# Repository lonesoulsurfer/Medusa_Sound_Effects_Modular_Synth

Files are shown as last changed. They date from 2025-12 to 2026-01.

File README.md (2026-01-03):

YJPQ4857

YouTube - https://youtu.be/EX9xcyuSX-U

Instructables - Step by step guide - https://www.instructables.com/Medusa-a-Sound-Effects-Synth-Eurorack-Module-or-St/

4 Main Knobs:

         Pot 1 (Pitch) - Controls the base frequency/note
    
         Pot 2 (Speed) - Controls how fast things move (LFO speed, tempo, etc.)

         Pot 3 (Modulation) - Controls effect intensity (vibrato, filter, etc.)
    
         Pot 4 (Echo Feedback) - Controls how much echo/delay repeats

Main Buttons:

          TRIGGER - Hold to play sound
          
          MENU - Cycles through 4 instruments (Dub Siren → Ray Gun → Lead Synth → Disco)
          
          MODE - Changes the sound variation within each instrument
          
         DELAY - Cycles delay time (OFF → 50ms → 100ms → 175ms → 250ms → 375ms)
         
          GATE - Changes gate length (how long notes are)
          
          OCTAVE - Shifts pitch up/down by octaves
          
          MUTATE - Cycles mutation modes (makes sound evolve randomly on each sync in trigger)

More details on the Mutate Function:

           Mutate works only with pitch and is controled by the pitch knob
           
           It will also only work with a sync in

           There are 3 sub menus
           
          1.  Mutation Probability (0-100%)
           
          2.  Rhythm - controls musical Scale Selection Cycles through: MIN PENT → MAJOR → BLUES → MINOR

          3.  Cutoff - Filter Cutoff (200-4000Hz)

           Mutate can be turned off by double tapping the mutate button and turned back on by tapping the mutate button
           Each function once set, is locked into place.

8 Keyboard Keys:

         Press keys 1-8 to play different notes in a musical scale

         Works like a mini keyboard - each key plays a specific pitch

         Also activates the special features

Instrument Guide

 1. DUB SIREN (Classic reggae/dub swoops)

         What each pot does:
         
         Pot 1 (PITCH) - Base frequency (50-2000Hz) - turn to change the note

         Pot 2 (SPEED) - LFO speed (0.1-20Hz) - how fast the sound wobbles

         Pot 3 (MOD) - Modulation depth (0-100%) - how much the pitch sweeps

         Pot 4 (Echo Feedback) - Echo repeats (0-95%) - for dub delays

6 Modes (press MODE button):

         CLASSIC DUB - Smooth sawtooth wobble
         
         DEEP SUB - Adds sub-bass octave (Pot 3 controls sub mix)
         
         SQUARE WAVE - Hollow, aggressive tone
         
         LO-FI CRUSH - Bit crusher effect (Pot 3 controls bit depth 1-8)
         
         RING MOD - Metallic ring modulation (Pot 3 controls ring mod frequency)
         
         PORTAMENTO - Smooth pitch glide (Pot 2 controls glide time)

2. RAY GUN (Sci-fi laser sounds)

         What each pot does:

         Pot 1 (FREQ) - Laser frequency (200-4000Hz) - pitch of the laser

         Pot 2 (SWEEP) - Sweep speed (0.1-20Hz) - how fast it swoops

         Pot 3 (RES) - Resonance (30-95%) - filter sharpness/brightness

         Pot 4 (Echo Feedback) - Echo repeats (0-95%)

         4 Modes (press MODE button):

         ZAP - Quick upward sweep (classic ray gun)

         LASER - Downward sweep with noise burst

         BLASTER - Rapid fire short bursts

         PHASER - Modulated pulse (sci-fi phaser)

3. LEAD SYNTH (Generative melodies)

         What each pot does:

         Pot 1 (ROOT) - Root note (200-800Hz) - base pitch of the melody

         Pot 2 (TEMPO) - Step speed (100-1000ms) - how fast notes play

         Pot 3 (VIB) - Vibrato depth (0-10%) - pitch wobble on notes

         Pot 4 (Gate) - Gate length (20-100%) - how long each note plays

         4 Modes (press MODE button):

         SEQUENCE - Plays pre-programmed melody

         ARPEGGIO - Arpeggiator with octave jumps

         EUCLIDEAN - Euclidean rhythm patterns

         GENERATIVE - Auto-generates new melodies

4. DISCO (Classic disco effects)

         What each pot does:

         Pot 1 (PITCH) - Base frequency (100-2000Hz) - effect pitch

         Pot 2 (SPEED) - Effect duration/speed - how long the effect lasts

         Pot 3 (BRIGHT) - Brightness (0-100%) - filter cutoff/tone

         Pot 4 (Echo Feedback) - Echo repeats (0-95%)

         6 Modes (press MODE button):

         ORCH HIT - Punchy orchestral stab

         STRINGS - Rising string machine sweep

         FUNK BLAST - Synth brass stab with pitch bend

         WHOOSH - Noise sweep (spaceship flyby)

         BUBBLE - Percussive bubble pop sound

         LASER - Musical laser sweep with vibrato

Special Features (Function + key buttons 1 - 8)

Sequencer  (Function + Key 1):

         Creates an 8-step programmable sequence

         Press keyboard keys to toggle steps on/off

         Hold a key to adjust that step's pitch with Pot 1

         TRIGGER starts/stops playback

Record  (Function + Key 3):

         Press Key 3 once to start recording (up to 5 seconds)

         Press Key 3 again to stop

         Press Key 3 again to play back

         Press Key 4 to toggle loop on/off

Reverse  (Function + Key 4):

         Press Key 4 to toggle reverse effect on/off

         Pot 1 controls pitch shift

         Pot 3 controls wet/dry mix

Infinite Delay (Function + Key 5):

         Press Key 5 to toggle infinite sustain on/off

         Pot 1: Feedback amount (95-100%) when hold is ON

         Pot 3: Filter cutoff

LFO 2 (Function + Key 6)

         Secondary LFO that modulates frequency for vibrato/tremolo effects

         Pot 1: LFO 2 Rate (0.1-20 Hz)

         Pot 3: LFO 2 Depth (0-100%)

         Press Key 6 to toggle LFO 2 ON/OFF

Drone (Function + Key 7)

         5-oscillator additive drone synthesizer with drift and detuning

         Press TRIGGER to cycle modes: OFF → KEYS → ON
         
         Pot 1: Root Pitch (20-400Hz)

         Pot 2: Detune Amount (0-100%) - spread between oscillators

         Pot 3: Brightness (0-100%) - timbre from dark to bright

         Pot 4: Drift Speed (0.1-5Hz) - slow LFO modulation

                  Press MODE button to cycle chord voicings:

                           UNISON: All oscillators at same pitch

                           OCTAVE: Root + octaves

                           FIFTH: Root + perfect fifth

                           MAJOR: Major chord (root, major 3rd, 5th)

                           MINOR: Minor chord (root, minor 3rd, 5th)

Sidechain (Function + Key 8)

         Classic "pumping" sidechain compression effect

         Press Key 8 to toggle SIDECHAIN ON/OFF

         Pot 1: Ducking Depth (0-100%) - how much volume reduction

         Pot 2: Attack Time (1-50ms) - how fast it ducks

         Pot 3: Release Time (50-500ms) - how fast it returns

         Syncs with LOOP patterns or SYNC input for rhythmic pumping

         Auto-retriggering creates continuous pumping effect

NOTE - all functions can be turned off by double tapping the Function button

EBXY7489

GSUT3404

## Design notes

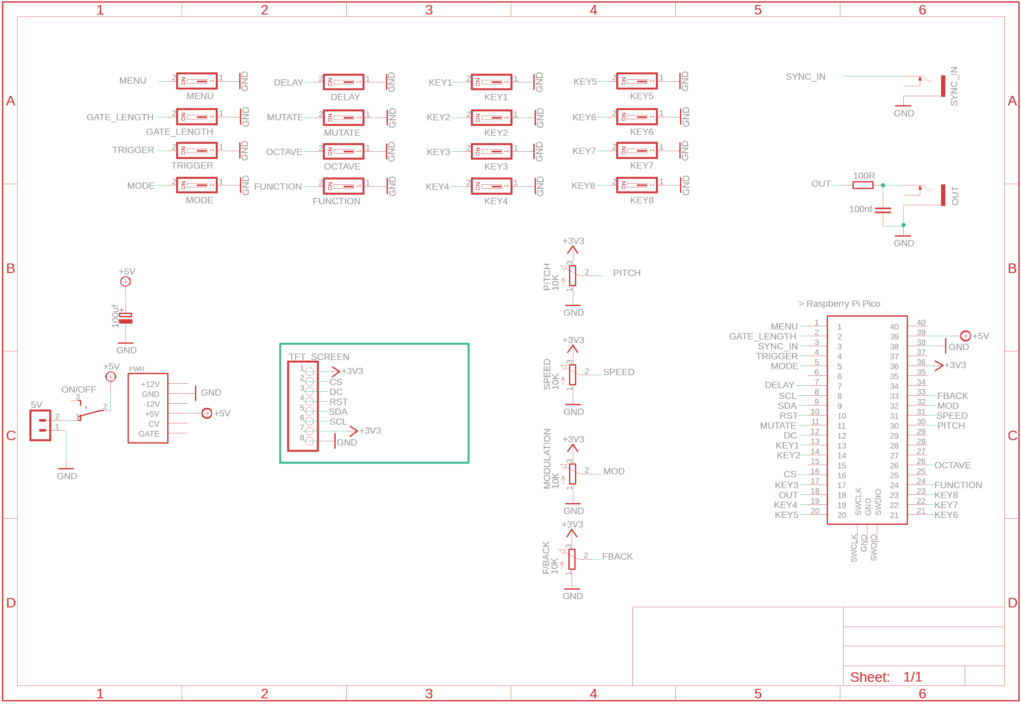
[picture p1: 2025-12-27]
Schematic.png

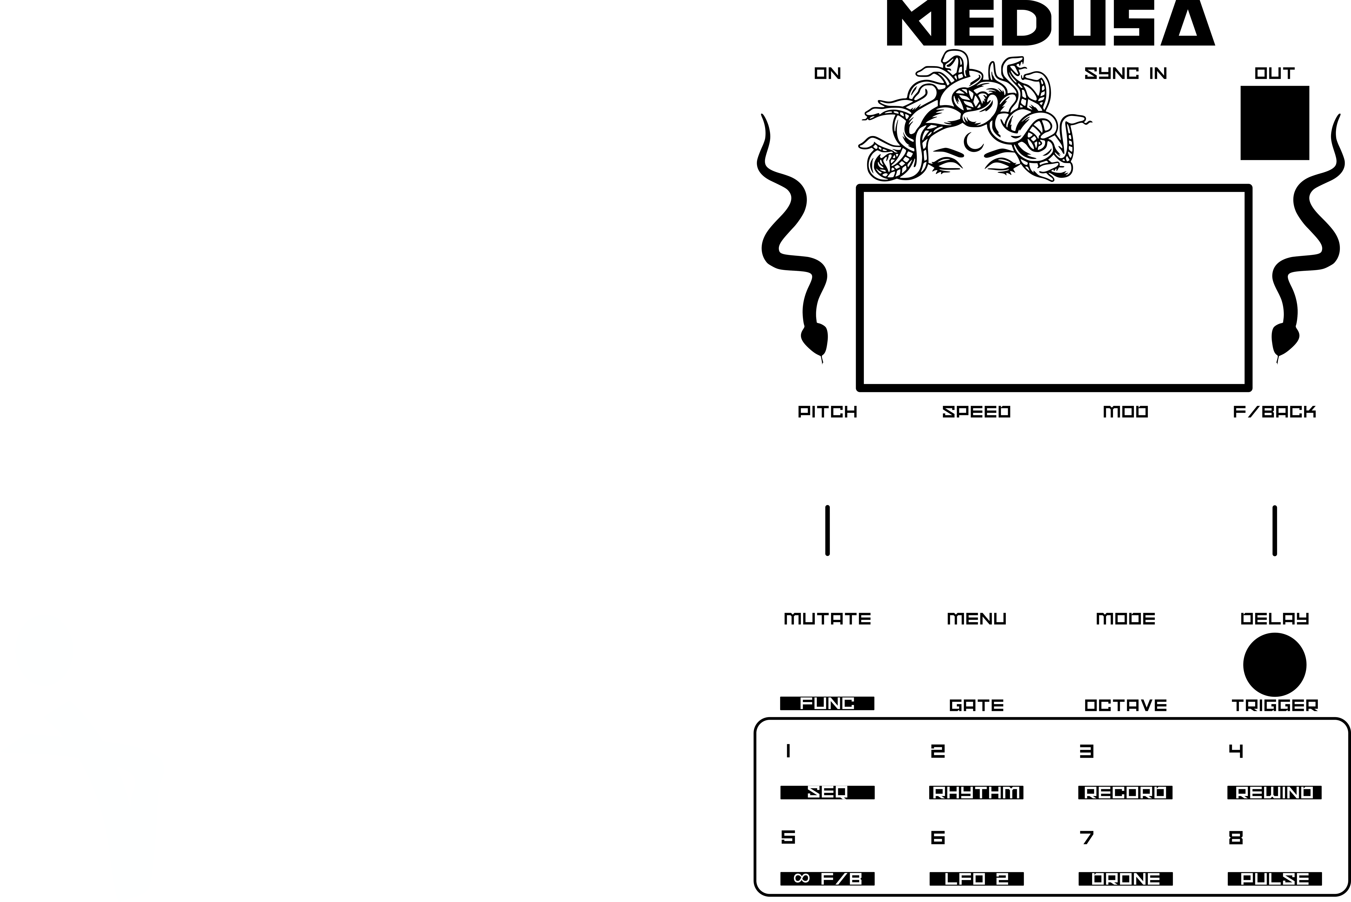
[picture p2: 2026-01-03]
Front Panel Design/Medusa -Front Panel Inkscape.png

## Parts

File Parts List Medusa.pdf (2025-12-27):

Part | Type | Part Number | Value | Qty | Link | Image
Mini JST Connector and wire | 2 pin | | 2 | 1 | Link (https://vi.aliexpress.com/item/1005005939956886.html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)
Capacitor | Polyester | | 100nf | 1 | Link (https://vi.aliexpress.com/w/wholesale-capacitor-100nf.html?spm=a2g0o.productlist.search.0)
| Electrolytic | | 100uf | 1 | Link (https://vi.aliexpress.com/w/wholesale-capacitor-100uf-.html?spm=a2g0o.productlist.search.0)
Switch | Momentary | SKRCADD010 | | 16 | Link (https://www.aliexpress.com/w/wholesale-SKRCADD010.html?spm=a2g0o.productlist.search.0)
| SPDT - Through Hole Version | | | 1 | Link (https://vi.aliexpress.com/item/1005001510219617.html)
Potentiometer | Verticle 9mm - Use the metal sharft type. You can use the nut on these to help secure the front panel to the PCB | | 10K | 4 | Link (https://www.aliexpress.com/w/wholesale-9mm-vertical-potentiometer.html)
Raspberry Pi Pico | Note that I used the Raspberry Pi that has 4 analog inputs. You need to get the exact one. See picture | | | 1 | Link (https://www.aliexpress.com/item/1005008614073097.html?curPageLogUid=pEBG9kNp92hi)
Female Header Pin Socket | 20 Pin | | | 3 | Link (https://vi.aliexpress.com/w/wholesale-Single-Row-Female-2.54MM-Spacing-Pin.html)
Male Header Pin | 7 Pin. These are used for the screen. The pins are 0.5mm | | | 1 | Link
Female header pin | 7 Pin. These are used for the screen. The pins are 0.5mm | | | 1 | Link
Audio Socket | | PJ301M | | 2 | Link (https://vi.aliexpress.com/item/1005005352992401.html?scm_id=1007.40050.354490.0&scm-url=1007.40050.354490.0)
Resistor | Metal film 1% | | 270R | 1 | Link (https://vi.aliexpress.com/w/wholesale-resistor-metal-film.html?spm=a2g0o.productlist.search.0)
TFT Screen | 1.9 Inch, 170x320 ST7789 | | | 1 | Link (https://www.aliexpress.com/w/wholesale-1.9-Inch-IPS-Full-Angle-TFT-Display-Screen-LCD-Scr.html)
M2 screws | | | | | Link (https://www.aliexpress.com/item/1005007159750547.html)
M2 Spacers | Nylon | | | | Link (https://www.aliexpress.com/w/wholesale-Nylon-Hex-Hexagon-Spacer-Column-Standoff-m2.html)

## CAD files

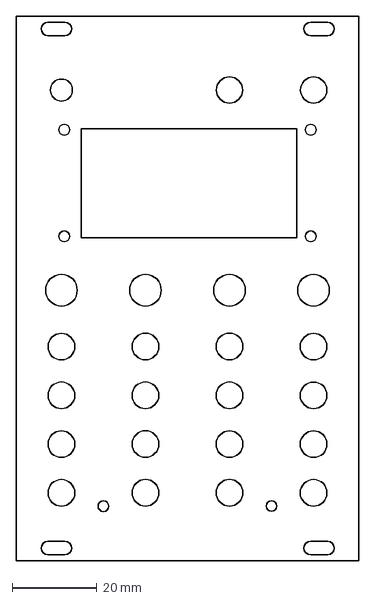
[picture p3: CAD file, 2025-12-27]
Front Panel Design/Medusa - Fusion.dxf
80.9 x 128.5 mm

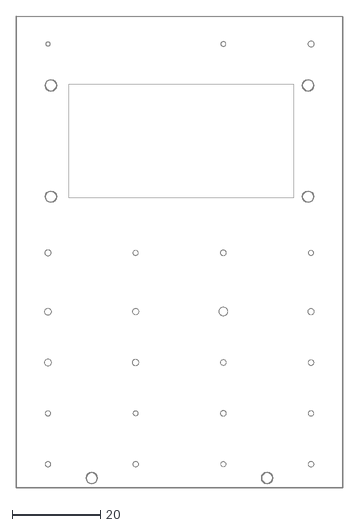
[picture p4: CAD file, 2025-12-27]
Front Panel Design/Medusa PCB.dxf
73.9 x 106.6

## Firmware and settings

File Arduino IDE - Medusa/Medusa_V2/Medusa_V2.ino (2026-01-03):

/*
 * =====================================================================
 *                    RP2040 DUB SIREN
 *              with Real-time Waveform Display
 *              RP2040-Zero + ST7789 170x320 TFT
 * =====================================================================
 * 
 * HARDWARE:
 * Waveshare RP2040-Zero
 * ST7789 170x320 TFT Display
 * 4 Potentiometers (10k recommended)
 * 2 Buttons (momentary)
 * Audio out via PWM
 * 
 * WIRING:
 * TFT Display:
 *   SCL -> GP6, SDA -> GP7
 *   RST -> GP8, DC -> GP10, CS -> GP13
 * 
 * Potentiometers (to 3.3V and GND):
 *   Pot 1 (Pitch)         -> GP26 (ADC0)
 *   Pot 2 (Speed)         -> GP27 (ADC1)
 *   Pot 3 (Modulation)    -> GP28 (ADC2)
 *   Pot 4 (Echo Feedback) -> GP29 (ADC3)
 * 
 * Buttons:
 *   Trigger Button (momentary) -> GP3
 *   Delay Time Button          -> GP5 (cycles through 5 delay times)
 *   Mode Button                -> GP4 (cycles through synthesis modes)
 * 
 * Sync Input:
 *   External Sync (3-5V)       -> GP2 (triggers sound when HIGH)
 * 
 * Audio Output:
 *   PWM Audio -> GP15 -> 100Ω resistor -> amplifier input
 * =====================================================================
 */

#include <SPI.h>
#include <Adafruit_GFX.h>
#include <Adafruit_ST7789.h>
#include <hardware/pwm.h>
#include <hardware/adc.h>

// =====================================================================
// PIN DEFINITIONS
// =====================================================================

// Display pins
#define TFT_CS        13
#define TFT_RST       8
#define TFT_DC        10
#define TFT_MOSI      7
#define TFT_SCK       6

// Potentiometer pins (ADC)
#define POT_PITCH     26  // ADC0
#define POT_SPEED     27  // ADC1
#define POT_MOD       28  // ADC2 - Modulation depth
#define POT_FEEDBACK  29  // ADC3 - Echo feedback

// Button pins
#define BTN_TRIGGER   3
#define BTN_DELAY     5   // Cycles through delay times
#define BTN_MODE      4   // Cycles through synthesis modes
#define BTN_FUNCTION  1   // Multi-function button (gate length, etc)
#define BTN_MENU      0   // MENU BUTTON - cycles instruments
#define BTN_MUTATE    9   // MUTATE BUTTON - cycles mutation modes
#define BTN_FUNC_SHIFT 21 // FUNCTION SHIFT - hold for alternative key functions

// Sync input
#define SYNC_IN       2   // External sync input (3-5V triggers sound)

// Keyboard pins (8 keys)
#define KEY_1         11  // Root note
#define KEY_2         12  // 2nd degree
#define KEY_3         14  // 3rd degree
#define KEY_4         16  // 4th degree
#define KEY_5         17  // 5th degree
#define KEY_6         18  // 6th degree
#define KEY_7         19  // 7th degree
#define KEY_8         20  // Octave/8th degree

// Octave shift button
#define BTN_OCTAVE    23  // Cycles octave shift

// Audio pin
#define AUDIO_PIN     15

// Display dimensions
#define SCREEN_WIDTH  320
#define SCREEN_HEIGHT 170

// Colors
#define COLOR_BG      0x0000
#define COLOR_WAVE    0x07E0  // Green
#define COLOR_GRID    0x2104  // Dark green
#define COLOR_TEXT    0xFFFF
#define COLOR_ACTIVE  0xF800  // Red
#define COLOR_ECHO    0x07FF  // Cyan
#define COLOR_MOD     0xFFE0  // Yellow

// =====================================================================
// AUDIO CONFIGURATION
// =====================================================================

#define SAMPLE_RATE 22050
#define PWM_WRAP 255

// Echo buffer - 500ms max delay at 22050 Hz
#define MAX_DELAY_SAMPLES 11025
int16_t echoBuffer[MAX_DELAY_SAMPLES];
uint16_t echoWritePos = 0;

// =====================================================================
// FORWARD DECLARATIONS
// =====================================================================

/**
 * Draw a labeled parameter value with color-coded label
 * @param x X position
 * @param y Y position
 * @param width Width of clear area
 * @param label Label text (will be colored MOD color)
 * @param value Value to display
 * @param suffix Optional suffix (Hz, ms, %, etc)
 * @param valueColor Color for value text (default: TEXT)
 */

void drawParameter(int x, int y, int width, const char* label, const char* value, const char* suffix = "", uint16_t valueColor = COLOR_TEXT);
void drawParameter(int x, int y, int width, const char* label, int value, const char* suffix = "", uint16_t valueColor = COLOR_TEXT);
void drawSubHeading(int y, const char* label, const char* value, uint16_t valueColor = COLOR_TEXT);
void drawSubHeadingOctave(int y, int8_t octaveValue);
void drawSubHeadingGatePercent(int y, uint8_t percentage);
void drawWaveform(bool forceRedraw = false);
void drawParameters(bool forceFullRedraw = false);
void updateKeyboardFrequencies();
void generateMelody();
float quantizePitchToScale(float baseFreq, uint8_t scaleStep);

// =====================================================================
// GLOBAL OBJECTS
// =====================================================================

Adafruit_ST7789 display = Adafruit_ST7789(&SPI, TFT_CS, TFT_DC, TFT_RST);
uint slice_num;

// =====================================================================
// INSTRUMENT TYPES
// =====================================================================

enum InstrumentType {
    INST_DUB_SIREN = 0,
    INST_RAY_GUN,
    INST_LEAD_SYNTH,
    INST_DISCO,
    INST_COUNT
};

const char* instrumentNames[INST_COUNT] = {
    "DUB SIREN",
    "RAY GUN",
    "LEAD SYNTH",
    "DISCO"
};

// =====================================================================
// SYNTHESIS MODES
// =====================================================================

enum SynthMode {
    MODE_CLASSIC_DUB = 0,
    MODE_DEEP_SUB,
    MODE_SQUARE_WAVE,
    MODE_LOFI_CRUSH,
    MODE_RING_MOD,
    MODE_PORTAMENTO,
    MODE_COUNT
};

const char* modeNames[MODE_COUNT] = {
    "CLASSIC DUB",
    "DEEP SUB",
    "SQUARE WAVE",
    "LO-FI CRUSH",
    "RING MOD",
    "PORTAMENTO"
};

// Ray Gun sub-modes
enum RayGunMode {
    RAYGUN_ZAP = 0,      // Quick upward sweep
    RAYGUN_LASER,        // Downward sweep
    RAYGUN_BLASTER,      // Short burst
    RAYGUN_PHASER,       // Modulated pulse
    RAYGUN_MODE_COUNT
};

const char* rayGunModeNames[RAYGUN_MODE_COUNT] = {
    "ZAP",
    "LASER",
    "BLASTER",
    "PHASER"
};

// Lead Synth sub-modes
enum LeadSynthMode {
    LEAD_SEQUENCE = 0,    // Auto-sequenced melody
    LEAD_ARPEGGIO,        // Arpeggiator
    LEAD_EUCLIDEAN,       // Euclidean rhythm patterns
    LEAD_GENERATIVE,      // Generative melody
    LEAD_MODE_COUNT
};

const char* leadSynthModeNames[LEAD_MODE_COUNT] = {
    "SEQUENCE",
    "ARPEGGIO",
    "EUCLIDEAN",
    "GENERATIVE"
};

// Disco sub-modes
enum DiscoMode {
    DISCO_ORCHESTRA_HIT = 0,  // Punchy orchestral stab
    DISCO_STRING_SWEEP,       // Rising string machine
    DISCO_FUNK_BLAST,         // Synth brass stab
    DISCO_SPACE_WHOOSH,       // Noise sweep (spaceship)
    DISCO_BUBBLE_POP,         // Percussive bubble sound
    DISCO_LASER_SWEEP,        // Musical laser sweep
    DISCO_MODE_COUNT
};

const char* discoModeNames[DISCO_MODE_COUNT] = {
    "ORCH HIT",
    "STRINGS",
    "FUNK BLAST",
    "WHOOSH",
    "BUBBLE",
    "PAD CHORD"
};

// Mutation modes
enum MutationMode {
    MUTATE_OFF = 0,
    MUTATE_AMOUNT,
    MUTATE_RHYTHM,
    MUTATE_CUTOFF,
    MUTATE_MODE_COUNT
};

const char* mutationModeNames[MUTATE_MODE_COUNT] = {
    "OFF",
    "MUTATE",
    "RHYTHM",
    "CUTOFF"
};

// Loop/Gate pattern modes
enum LoopPattern {
    LOOP_OFF = 0,
    LOOP_TRIPLET,    // ███░░░███░░░ (triplet feel - 3 against 2)
    LOOP_SWING,      // ██░██░░██░ (swing/shuffle - classic dub feel)
    LOOP_STACCATO,   // █░░█░░█░░ (short stabs)
    LOOP_GATE,       // ████░░░░ (gate on first half, off second)
    LOOP_RATCHET,    // █░█░█░█░█░█░ (fast machine gun)
    LOOP_DOTTED,     // ██░█░██░█░ (dotted eighth feel)
    LOOP_COUNT
};

const char* loopPatternNames[LOOP_COUNT] = {
    "OFF",
    "TRIPLET",
    "SWING",
    "STACCATO",
    "GATE",
    "RATCHET",
    "DOTTED"
};

// Loop pattern state
struct LoopState {
    bool active;                  // Is loop mode active?
    uint8_t pattern;              // Current loop pattern
    unsigned long patternStartTime; // When current pattern cycle started
    uint16_t patternTempo;        // Pattern speed in ms (full cycle time)
    bool gateState;               // Current gate on/off state
};

LoopState loopState = {
    false,        // active
    LOOP_OFF,     // pattern
    0,            // patternStartTime
    480,          // patternTempo (480ms = 125 BPM, classic dub tempo)
    false         // gateState
};

// =====================================================================
// SEQUENCER STATE
// =====================================================================

struct SequencerState {
    bool active;              // Is sequencer mode active?
    bool running;             // Is sequencer playing?
    bool stepEnabled[8];      // Which steps are on/off
    float stepFrequencies[8]; // Frequency for each step
    uint8_t currentStep;      // Current playback position (0-7)
    unsigned long lastStepTime; // Timing for steps
    uint16_t stepInterval;    // ms between steps (from Pot 2)
    bool noteActive;          // Is current note playing
    uint32_t sequencerPhase;  // Sequencer oscillator phase
    uint8_t gateLength;       // Gate length percentage (20-100%)
    unsigned long noteStartTime; // When current note started
    uint16_t filterCutoff;    // Filter cutoff frequency (200-4000)
    int8_t octaveShift;       // Octave shift for sequencer (-2 to +2)
    uint8_t soundMode;        // Sound variation mode
};

SequencerState sequencer = {
    false,                    // active
    false,                    // running
    {true, true, true, true, true, true, true, true}, // All steps enabled initially
    {0,0,0,0,0,0,0,0},       // stepFrequencies (will be set from keyboard)
    0,                        // currentStep
    0,                        // lastStepTime
    250,                      // stepInterval (250ms default)
    false,                    // noteActive
    0,                        // sequencerPhase
    80,                       // gateLength (80% default)
    0,                        // noteStartTime
    1200,                     // filterCutoff (1200 default - warm tone)
    0,                        // octaveShift (start at 0)
    0                         // soundMode (SAW mode default)
};

// Sequencer sound modes
enum SequencerSoundMode {
    SEQ_SOUND_SAW = 0,     // Sawtooth/square mix (current)
    SEQ_SOUND_PULSE,       // Pulse width modulation
    SEQ_SOUND_FILTERED,    // Heavy filtered bass
    SEQ_SOUND_PLUCK,       // Plucked envelope
    SEQ_SOUND_CHORD,       // Add 5th harmonic
    SEQ_SOUND_COUNT
};

const char* seqSoundModeNames[SEQ_SOUND_COUNT] = {
    "SAW",
    "PULSE",
    "FILTERED",
    "PLUCK",
    "CHORD"
};

// Musical scales for pitch quantization (frequency ratios)
const float minorPentatonic[] = {1.0f, 1.189f, 1.335f, 1.498f, 1.782f, 2.0f}; // Root, m3, 4, 5, m7, octave
const uint8_t minorPentatonicSize = 6;

const float majorScale[] = {1.0f, 1.122f, 1.260f, 1.335f, 1.498f, 1.682f, 1.888f, 2.0f}; // Major scale
const uint8_t majorScaleSize = 8;

const float bluesScale[] = {1.0f, 1.189f, 1.260f, 1.335f, 1.498f, 1.782f, 2.0f}; // Blues scale
const uint8_t bluesScaleSize = 7;

const float minorScale[] = {1.0f, 1.122f, 1.189f, 1.335f, 1.498f, 1.587f, 1.782f, 2.0f}; // Natural minor
const uint8_t minorScaleSize = 8;

const float chromaticScale[] = {1.0f, 1.059f, 1.122f, 1.189f, 1.260f, 1.335f, 1.414f, 1.498f, 1.587f, 1.682f, 1.782f, 1.888f, 2.0f}; // All 12 notes
const uint8_t chromaticScaleSize = 13;

// Musical scales for mutation
enum MutationScale {
    SCALE_MINOR_PENT = 0,
    SCALE_MAJOR,
    SCALE_BLUES,
    SCALE_MINOR,
    SCALE_CHROMATIC,
    SCALE_COUNT
};

const char* scaleNames[SCALE_COUNT] = {
    "MIN PENT",
    "MAJOR",
    "BLUES",
    "MINOR",
    "CHROMATIC"
};

// Mutation state
struct MutationState {
    uint8_t mode;           // Current mutation mode
    uint8_t pitchStep;      // Current step in scale
    uint8_t speedStep;      // Current speed quantization step
    float mutationProbability; // Chance of mutation (0.0-1.0)
    unsigned long lastMutateTime; // Last time mutation occurred
    uint8_t currentScale;   // Current scale being used
    
    // Parameter locking
    uint16_t lockedProbabilityRaw;  // Locked pot value for probability
    uint16_t lockedScaleRaw;        // Locked pot value for scale
    uint16_t lockedCutoffRaw;       // Locked pot value for cutoff
    bool probabilityLocked;         // Is probability parameter locked?
    bool scaleLocked;               // Is scale parameter locked?
    bool cutoffLocked;              // Is cutoff parameter locked?
    bool fullyDisabled;             // Are all mutations disabled? (ADD THIS LINE)
};

MutationState mutate = {
    MUTATE_OFF,     // mode
    0,              // pitchStep (start at root)
    2,              // speedStep (start at medium speed)
    0.5f,           // mutationProbability (50% chance)
    0,              // lastMutateTime
    SCALE_MINOR_PENT, // currentScale (minor pentatonic default)
    
    // Initialize locks
    2048,           // lockedProbabilityRaw (middle position)
    2048,           // lockedScaleRaw (middle position)
    2048,           // lockedCutoffRaw (middle position)
    false,          // probabilityLocked
    false,          // scaleLocked
    false,          // cutoffLocked
    false           // fullyDisabled (ADD THIS LINE)
};

// Drone chord modes
enum DroneChordMode {
    DRONE_UNISON = 0,
    DRONE_OCTAVE,
    DRONE_FIFTH,
    DRONE_MAJOR,
    DRONE_MINOR,
    DRONE_CHORD_COUNT
};

const char* droneChordModeNames[DRONE_CHORD_COUNT] = {
    "UNISON",
    "OCTAVE",
    "FIFTH",
    "MAJOR",
    "MINOR"
};

// Drone synth state
struct DroneState {
    bool active;              // Is drone mode active?
    uint8_t playMode;         // Play mode: 0=OFF, 1=KEYS, 2=ON
    float rootFreq;           // Base frequency (20-400Hz)
    float detune;             // Detune amount (0.0-1.0)
    float brightness;         // Timbre control (0.0-1.0)
    float driftSpeed;         // LFO drift rate (0.1-5Hz)
    uint32_t oscPhases[5];    // Phase accumulators for each oscillator
    float oscDetunes[5];      // Detune offset for each osc (-1.0 to +1.0)
    uint32_t driftPhases[5];  // Slow LFOs for drift
    float envelope;           // Fade in/out envelope (0.0-1.0)
    unsigned long fadeStartTime; // When fade started
    uint8_t chordMode;        // Current chord mode
};

DroneState drone = {
    false,      // active
    0,          // playMode (0=OFF to start)
    110.0f,     // rootFreq (A2)
    0.3f,       // detune (30% default)
    0.6f,       // brightness (60% default)
    1.0f,       // driftSpeed (1Hz default)
    {0,0,0,0,0}, // oscPhases
    {-0.02f, -0.01f, 0.0f, 0.01f, 0.02f}, // oscDetunes (slight spread)
    {0,0,0,0,0}, // driftPhases
    0.0f,       // envelope (start silent)
    0,          // fadeStartTime
    0           // chordMode (UNISON default)
};

// Sidechain state
struct SidechainState {
    bool active;              // Is sidechain mode active?
    bool enabled;             // Is sidechain currently ON?
    float depth;              // Ducking amount (0.0-1.0)
    float attackTime;         // Attack time in ms (1-50ms)
    float releaseTime;        // Release time in ms (50-500ms)
    float envelope;           // Current envelope value (0.0-1.0)
    unsigned long lastTriggerTime; // When last trigger occurred
    bool triggered;           // Is currently triggered
};

SidechainState sidechain = {
    false,      // active
    false,      // enabled
    0.9f,       // depth (90% ducking default - MORE OBVIOUS)
    3.0f,       // attackTime (3ms - FASTER attack for punch)
    300.0f,     // releaseTime (300ms - longer release for classic pump)
    1.0f,       // envelope (start at full volume)
    0,          // lastTriggerTime
    false       // triggered
};

// Drone display tracking (global so loop1 can force updates)
uint8_t lastDronePlayMode = 255;
bool forceDisplayUpdate = false;  // Flag to force display redraw

// =====================================================================
// RECORDING STATE
// =====================================================================

#define MAX_RECORD_SAMPLES 110250  // 5 seconds at 22050 Hz

struct RecordState {
    bool active;                    // Is record mode active?
    bool recording;                 // Is currently recording?
    bool hasRecording;              // Is there a recording to play?
    int16_t* buffer;                // Recording buffer (allocated dynamically)
    uint32_t recordPosition;        // Current record/playback position
    uint32_t recordLength;          // Length of recording in samples
    bool playing;                   // Is playback active?
    unsigned long recordStartTime;  // When recording started
    bool loopEnabled;               // Is loop/repeat enabled?
};

RecordState recorder = {
    false,      // active
    false,      // recording
    false,      // hasRecording
    nullptr,    // buffer (will allocate in setup)
    0,          // recordPosition
    0,          // recordLength
    false,      // playing
    0,          // recordStartTime
    false       // loopEnabled
};

// Flag to suppress sound during record mode key presses
bool recordKeySilence = false;

// =====================================================================
// REVERSE STATE
// =====================================================================

#define MAX_REVERSE_SAMPLES 11025  // 500ms at 22050 Hz

struct ReverseState {
    bool active;                    // Is reverse mode active?
    bool reversing;                 // Is reverse currently ON?
    int16_t* buffer;                // Reverse buffer (allocated dynamically)
    uint32_t bufferSize;            // Size in samples
    uint32_t writePos;              // Current write position
    float mixAmount;                // Wet/dry mix (0.0=dry, 1.0=wet)
    int8_t pitchShift;              // Pitch shift (-2 to +2 octaves)
};

ReverseState reverser = {
    false,      // active
    false,      // reversing
    nullptr,    // buffer (will allocate in setup)
    MAX_REVERSE_SAMPLES,  // bufferSize
    0,          // writePos
    1.0f,       // mixAmount (100% wet default)
    -1          // pitchShift (-1 octave default)
};

// =====================================================================
// INFINITE HOLD STATE
// =====================================================================

bool infiniteSustain = false;
bool holdIsOn = false;  // Track if hold is currently ON
float savedFeedback = 0.0f;

// =====================================================================
// LFO 2 STATE
// =====================================================================

struct LFO2State {
    bool active;            // Is LFO 2 mode active?
    bool enabled;           // Is LFO 2 currently ON?
    float rate;             // LFO 2 rate (0.1-20 Hz)
    float depth;            // LFO 2 depth (0.0-1.0)
    uint32_t phase;         // LFO 2 phase accumulator
};

LFO2State lfo2 = {
    false,      // active
    false,      // enabled
    2.0f,       // rate (2 Hz default)
    0.5f,       // depth (50% default)
    0           // phase
};

// =====================================================================
// SYNTH PARAMETERS
// =====================================================================
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
void loop() {
    readButtons();        // Read buttons FIRST
    readKeyboard();       // Read keyboard keys
    readPotentiometers(); // Then read pots (which checks button hold state)
    
    // Check if audio core requested display update
    if (forceDisplayUpdate) {
        drawParameters();  // Force immediate update
        forceDisplayUpdate = false;  // Clear flag
    }
    
    updateDisplay();
    
    // No delay - maximum responsiveness for trigger button
}
